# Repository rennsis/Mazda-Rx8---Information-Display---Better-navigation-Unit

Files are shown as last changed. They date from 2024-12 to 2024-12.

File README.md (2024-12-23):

In this project i want to share my work for the Mazda RX8 information diplay and the parts that connected to it.

I started the project while working on a "remake" for the navigation unit. Basiclly i want to replace the OEM Navigation unit with an own programmed display where u can see sensors and also troubleshoot your car for example a DTC read out.

Some information in the project i got from already dead github projects. So i will try to continue there work :) Also i alredy want to say thanks to these poeple who was able to help me with there information! 

Currently there wont be much in this Project cause im currently planing on desinging a PCB where everthing will connect. 

| ICON | DATA | ADDRESS |
| --- | --- | --- |
| CD-IN | 0x10 | 0x93 |
| MD-IN | 0x10 | 0x94 |
| L-DIVIDER | 0x10 | 0x91 |
| R-DIVIDER | 0x08 | 0x9B |
| ST | 0x10 | 0x95 |
| DA | 0x01 | 0x95 |
| C° | 0x10 | 0x96 |
| F° | 0x08 | 0x96 |
| TEMP | 0x04 | 0x96 |
| AMB | 0x02 | 0x96 |
| AF | 0x01 | 0x96 |
| CAR | 0x01 | 0x97 |
| PTY | 0x02 | 0x97 |
|  AIR-IN | 0x04 | 0x97 |
| AIR-REUSE | 0x08 | 0x97 |
| AUTO | 0x10 | 0x97 |
| FAN | 0x02 | 0x99 |
| FAN-1 | 0x04 | 0x99 |
| FAN-2 | 0x08 | 0x99 |
| FAN-3 | 0x10 | 0x99 |
| FAN-4 | 0x01 | 0x98 |
| FAN-5 | 0x04 | 0x98 |
| FAN-6 | 0x08 | 0x9D |
| FAN-7 | 0x02 | 0x9B |
| RPT | 0x20 | 0x98 |
| AC | 0x08 | 0x98 |
| ECO | 0x10 | 0x98 |
| AUTO-M | 0x01 | 0x9A |
| TP | 0x02 | 0x9A |
| TA | 0x04 | 0x9A |
| RDM | 0x08 | 0x9A |
| TEXT " | 0x04 | 0x9B |
| TEXT : | 0x10 | 0x9D |
| TEXT-R . | 0x10 | 0x9B |
| PERSON | 0x01 | 0x9C |
| FRONT-HEAT | 0x02 | 0x9C |
| ARROW-FEED | 0x04 | 0x9C |
| ARROW-FACE | 0x04 | 0x9D |
| TMP . | 0x02 | 0x9D |
| CLOCK : | 0x04 | 0x93 |
| CLOCK . | 0x04 | 0x90 |

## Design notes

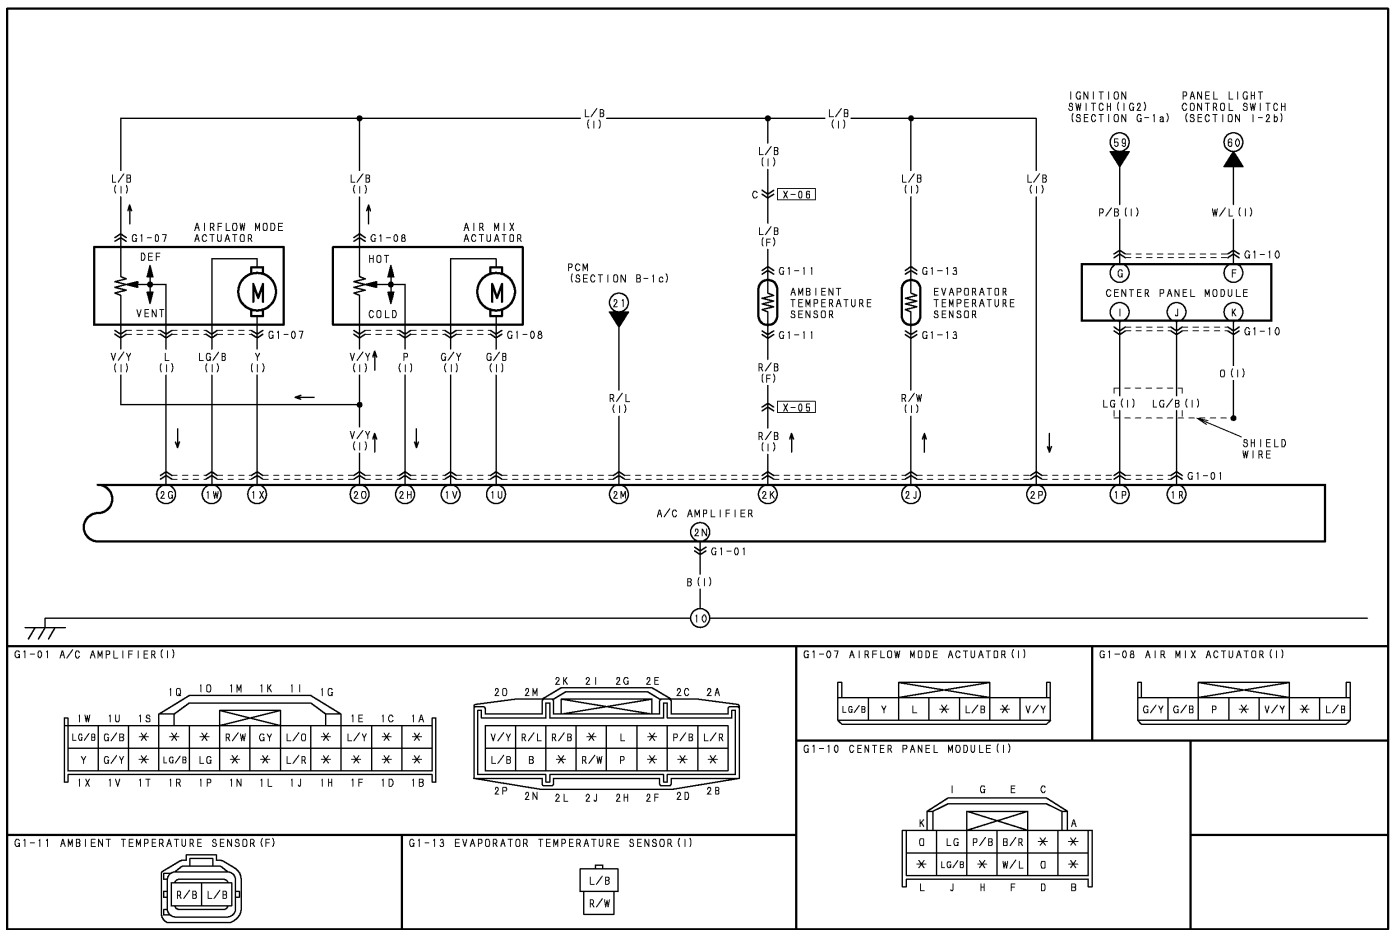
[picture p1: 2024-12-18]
AC Amplifier Connectors.png

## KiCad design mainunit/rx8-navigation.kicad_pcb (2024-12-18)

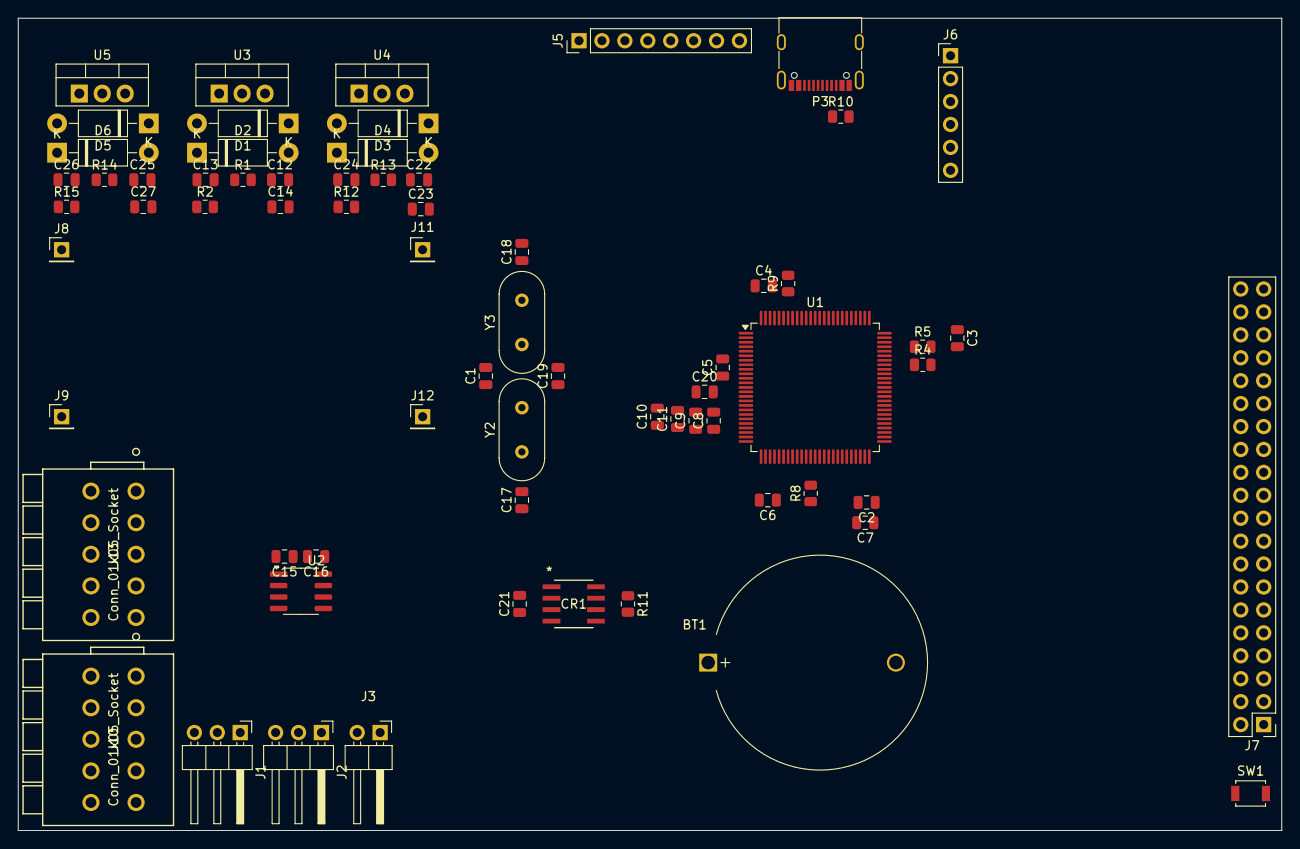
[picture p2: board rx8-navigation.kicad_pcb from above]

Board: 4 copper layers, 140.0 x 90.0 mm, 68 parts (0 on the bottom side), 62 nets, no tracks yet.

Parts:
BT1: Battery_Cell; BatteryHolder_MYOUNG_BS-07-A1BJ001_CR2032
C1, C17: 10pF; C_SMD
C2, C3, C4, C5, C6, C15, C16, C21: 100nF; C_SMD
C7: 4.7uF; C_SMD
C8, C10: 10nF; C_SMD
C9, C11, C14, C23, C27: 1uF; C_SMD
C12, C20, C22, C25: 0.1uF; C_SMD
C13, C24, C26: 10uF; C_SMD
C18, C19: 20pF; C_SMD
CR1: L9616; SO-8_STM
D1, D2, D3, D4, D5, D6: 1N4001; D_DO-41_SOD81_P10.16mm_Horizontal
J1: BOOT1; PinHeader_1x03_P2.54mm_Horizontal
J2: BOOT0; PinHeader_1x03_P2.54mm_Horizontal
J3: RX/TX; PinHeader_1x02_P2.54mm_Horizontal
J5: MPU-69050; PinHeader_1x08_P2.54mm_Vertical
J6: HC-06; PinHeader_1x06_P2.54mm_Vertical
J7: TFT_Unit; PinHeader_2x20_P2.54mm_Vertical
J8: RegV_IN+; PinHeader_1x01_P2.54mm_Vertical
J9: RegV_IN-; PinHeader_1x01_P2.54mm_Vertical
J10, J13: Conn_01x05_Socket; 2601-1105
J11: RegV_OUT+; PinHeader_1x01_P2.54mm_Vertical
J12: RegV_OUT-; PinHeader_1x01_P2.54mm_Vertical
P3: USB_C_Plug_USB2.0; USB_C_Receptacle_G-Switch_GT-USB-7010ASV
R1, R14: 180; R_SMD
R2, R12, R15: 110; R_SMD
R4, R5: 22; R_SMD
R8, R9: 10k; R_SMD
R10: 5.1k; R_SMD
R11: 120; R_SMD
R13: 330; R_SMD
SW1: RESET; SW_SPST_B3U-1000P
U1: STM32F103VBTx; LQFP-100_14x14mm_P0.5mm
U2: ZXBM5210-S; SOIC-8_3.9x4.9mm_P1.27mm
U3, U4, U5: LM317_TO-220; TO-220-3_Vertical
Y2: 32.768kHz; Crystal_HC18-U_Vertical
Y3: 8MHz; Crystal_HC18-U_Vertical

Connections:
+3.3V: C2.1, C3.1, C4.1, C5.1, C6.1, C7.1, C8.1, C9.1, C10.1, C11.1, C14.1, C15.2, C21.1, C27.1, CR1.3 (VS), D1.2 (A), D2.1 (K), D5.2 (A), D6.1 (K), J1.3, J2.3, J7.29, J10.1, R2.1, R15.1, U1.11 (VDD), U1.21 (VREF+), U1.22 (VDDA), U1.28 (VDD), U1.50 (VDD), U1.75 (VDD), U1.100 (VDD), U2.3 (VDD), U2.6 (VREF), U3.2 (VO), U5.2 (VO)
+5V: C12.1, C23.1, D1.1 (K), D3.2 (A), D4.1 (K), J5.8, J7.5, P3.A4 (VBUS), P3.A9 (VBUS), P3.B4 (VBUS), P3.B9 (VBUS), R12.1, U3.3 (VI), U4.2 (VO)
+12V: C22.1, C25.1, D3.1 (K), D5.1 (K), J11.1, U4.3 (VI), U5.3 (VI)
+BATT: BT1.1 (+), U1.6 (VBAT)
BOOT0: R9.2, U1.94 (BOOT0)
CAN_H: CR1.7 (C_H), J13.7, R11.1
CAN_L: CR1.6 (C_L), J13.9, R11.2
F_CS: J7.9, U1.57 (PD10)
GND: BT1.2 (-), C1.2, C2.2, C3.2, C4.2, C5.2, C6.2, C7.2, C8.2, C9.2, C10.2, C11.2, C12.2, C13.2, C14.2, C15.1, C16.1, C17.1, C18.2, C19.1, C20.1, C21.2, C22.2, C23.2, C24.2, C25.2, C26.2, C27.2, CR1.2 (GND), CR1.8 (ASC), J1.1, J2.1, J5.7, J6.3, J7.39, J9.1, J10.9, J12.1, J13.3, P3.A1 (GND), P3.A12 (GND), P3.B1 (GND), P3.B12 (GND), P3.S1 (SHIELD), R1.2, R10.2, R13.2, R14.2, SW1.2, U1.10 (VSS), U1.19 (VSSA), U1.20 (VREF-), U1.27 (VSS), U1.49 (VSS), U1.74 (VSS), U1.99 (VSS), U2.8 (GND)
HC_RXD: J6.5, U1.25 (PA2)
HC_TXD: J6.4, U1.26 (PA3)
I2C_SCL: J5.6, U1.92 (PB6)
I2C_SDA: J5.5, U1.93 (PB7)
MOTOR_B: U1.79 (PC11), U2.5 (REV)
MOTOR_GND: J10.7, U2.1 (OUT1)
MOTOR_POS: J10.3, U1.80 (PC12)
MOTOR_VDD: J10.5, U2.7 (OUT2)
NRST: C20.2, SW1.1, U1.14 (NRST)
unnamed: C13.1, D2.2 (A), R1.1, R2.2, U3.1 (ADJ)
unnamed: C24.1, D4.2 (A), R12.2, R13.1, U4.1 (ADJ)
unnamed: C26.1, D6.2 (A), R14.1, R15.2, U5.1 (ADJ)
unnamed: J1.2, R8.1
unnamed: J2.2, R9.1
unnamed: P3.A5 (CC), R10.1
unnamed: R4.1, U1.70 (PA11)
unnamed: R5.1, U1.71 (PA12)
unnamed: C16.2, U2.2 (VM)
OSC_IN: C18.1, U1.12 (OSC_IN), Y3.2
OSC_OUT: C19.2, U1.13 (OSC_OUT), Y3.1
PB_2 / BOOT1: R8.2, U1.37 (PB2)
PC14: C1.1, U1.8 (PC14), Y2.2
PC15: C17.2, U1.9 (PC15), Y2.1
RX / PA10: J3.2, U1.69 (PA10)
SD_CS: J7.6, U1.58 (PD11)
SPI_MISO: J7.12, J7.16, U1.31 (PA6)
SPI_MOSI: J7.4, J7.8, J7.20, U1.32 (PA7)
SPI_SCK: J7.2, J7.10, J7.24, U1.30 (PA5)
TFT_CS: J7.11, U1.55 (PD8)
TFT_DB0: J7.40, U1.88 (PD7)
TFT_DB1: J7.38, U1.87 (PD6)
TFT_DB2: J7.36, U1.86 (PD5)
TFT_DB3: J7.34, U1.85 (PD4)
TFT_DB4: J7.32, U1.84 (PD3)
TFT_DB5: J7.30, U1.82 (PD1)
TFT_DB6: J7.28, U1.81 (PD0)
TFT_DB7: J7.26, U1.46 (PE15)
TFT_DB8: J7.27, U1.45 (PE14)
TFT_DB9: J7.25, U1.44 (PE13)
TFT_DB10: J7.23, U1.43 (PE12)
TFT_DB11: J7.21, U1.42 (PE11)
TFT_DB12: J7.19, U1.41 (PE10)
TFT_DB13: J7.17, U1.40 (PE9)
TFT_DB14: J7.15, U1.39 (PE8)
TFT_DB15: J7.13, U1.38 (PE7)
TFT_RESET: J7.7, U1.62 (PD15)
TFT_RS: J7.33, U1.60 (PD13)
TFT_WR: J7.31, U1.61 (PD14)
TX / PA9: J3.1, U1.68 (PA9)
T_CS: J7.22, U1.59 (PD12)
USB_D+: P3.A6 (D+), R5.2
USB_D-: P3.A7 (D-), R4.2
VDD: J8.1, J13.1

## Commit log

2024-12-18 Added AC Connector Image
2024-12-18 Added PCB Schematic and PCB
    [rx8-navigation.kicad_pcb, rx8-navigation.kicad_sch]

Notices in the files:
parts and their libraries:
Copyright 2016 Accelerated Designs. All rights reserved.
